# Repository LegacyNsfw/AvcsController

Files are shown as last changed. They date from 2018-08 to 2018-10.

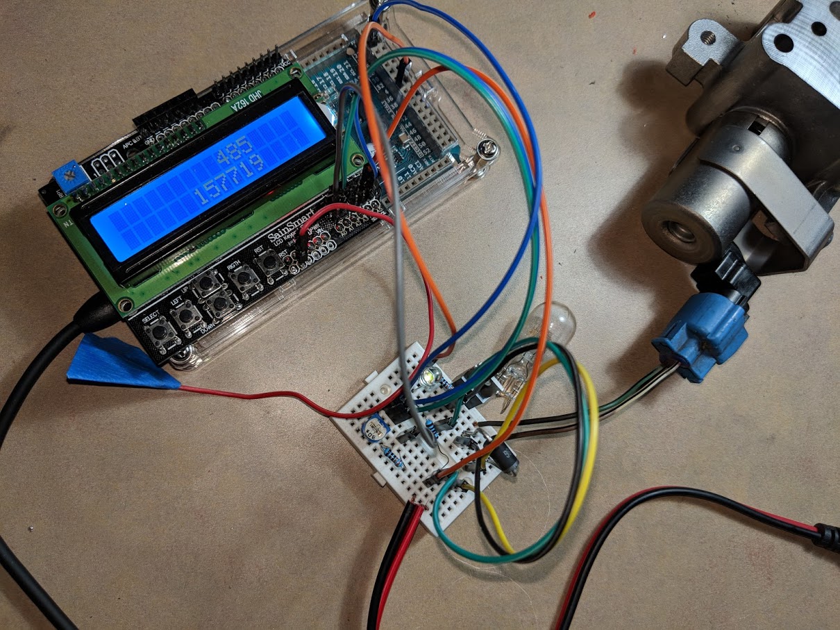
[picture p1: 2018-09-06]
Images/Hardware_SolenoidTesting.jpg

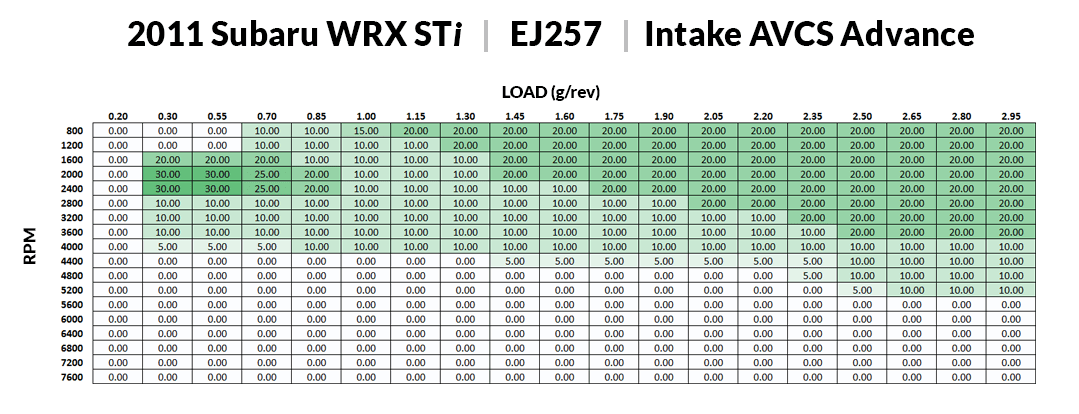
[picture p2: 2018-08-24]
Docs/subaru-avcs-intake-advance.png

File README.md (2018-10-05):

# AVCS Controller

A stand-alone exhaust AVCS controller for Subaru engines, based on an Arduino Due.

See the wiki for documentation.

See [this thread at RomRaider.com](http://www.romraider.com/forum/viewtopic.php?f=7&t=11237) for discussion.

All source code is licensed under the GNU GPL, version 3.

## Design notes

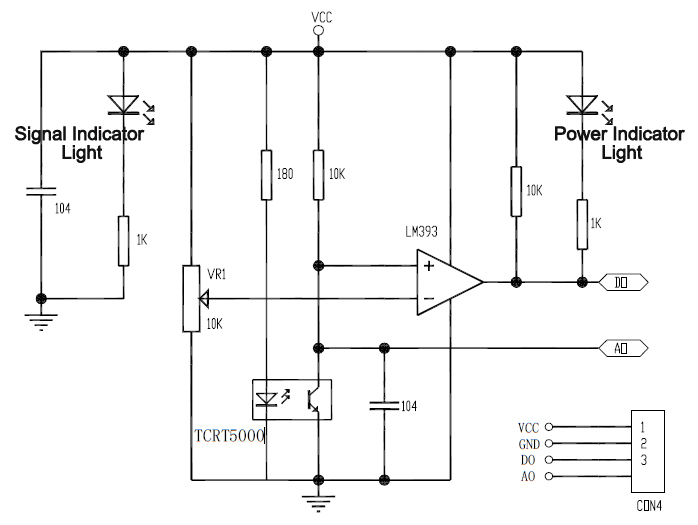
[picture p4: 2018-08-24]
Schematics/TCRT5000_LM393_Board.jpg

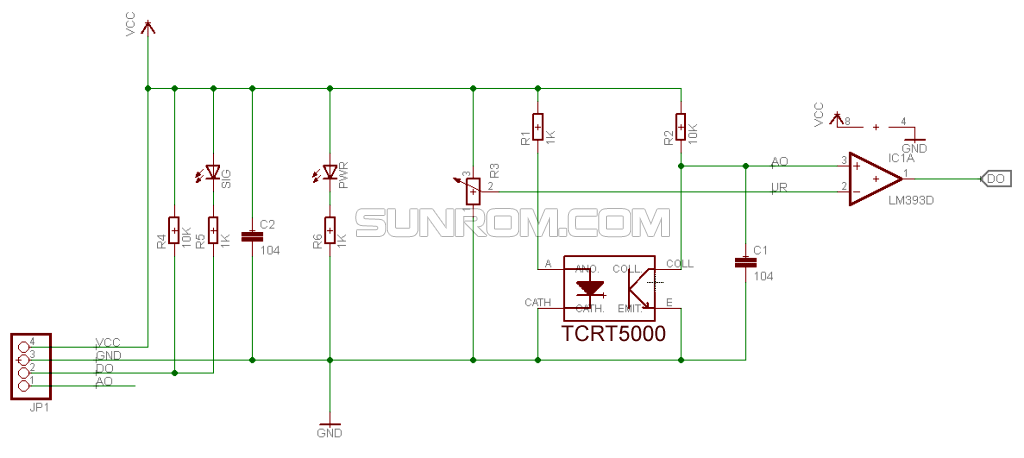
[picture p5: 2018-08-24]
Schematics/tcrt5000-schematic.gif

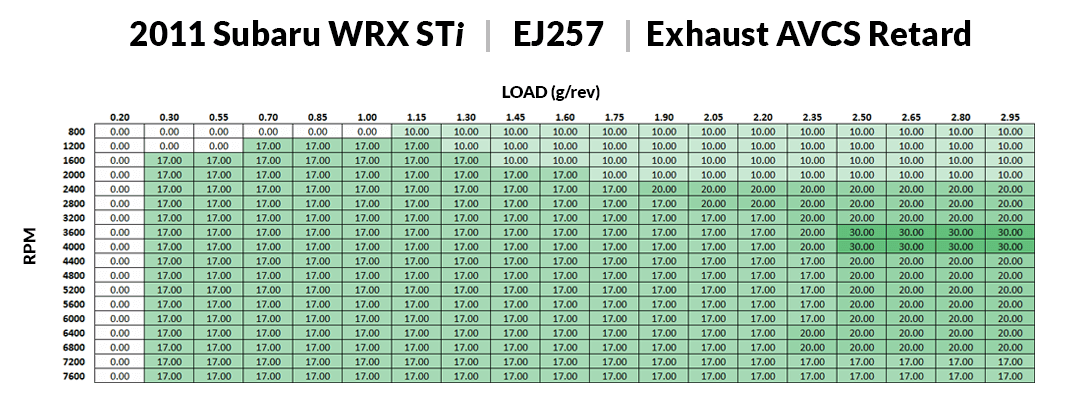
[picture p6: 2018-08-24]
Docs/subaru-avcs-exhaust-retard.png

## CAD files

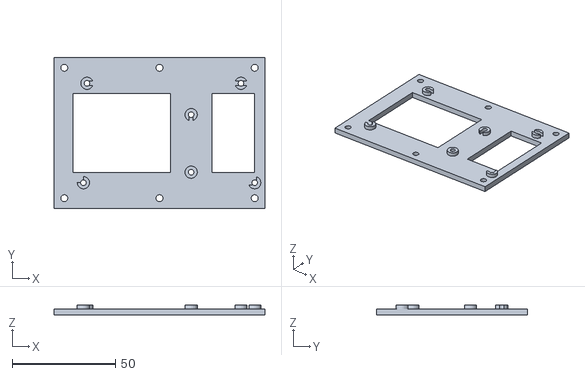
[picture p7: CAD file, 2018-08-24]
Models/ArduinoDueTwoPass.stl
102.3 x 73.2 x 5.00

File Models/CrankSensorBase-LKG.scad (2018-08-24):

width = 40;
height = 30;
baseDepth = 5;
lidDepth = 10;
ridgeTopWidth = 7;
ridgeBottomWidth = 10;
ridgeSpacing = 15;
ridgeHeight = 1.4;
mainHoleSpacing = 20;
thirdHoleSpacing = 17;
mainHoleDistanceFromEdge = 6;

sensorHoleCenter = 12.5; 
sensorWidth = 6.5;
sensorHeight = 11;

pulleyRadius = 48;
pulleyX = 41;
pulleyY = 40;

$fn = 20;

delta = 0;

module mountingHole(lid)
{
    cylinder(r = 1.6, h = 100, center = true);
    
    if (lid)
    {
        delta = 2.001;
    }
    else
    {
        delta = 1.999;
    }
    
    translate([0, 0, baseDepth + delta])
        cylinder(r = 3.4, h = 4, $fn = 6, center = true);
}

module holes(lid)
{
    translate([-17.5, 0, 0])
    {
        translate([mainHoleDistanceFromEdge, mainHoleSpacing / 2, 0])
        {
            mountingHole(lid);
        }

        translate([mainHoleDistanceFromEdge + thirdHoleSpacing, mainHoleSpacing / 2, 0])
        {
            mountingHole(lid);
        }

        translate([mainHoleDistanceFromEdge, -mainHoleSpacing / 2, 0])
        {
            mountingHole(lid);
        }
    }
}

module ridge()
{
    translate([-25, 0, -0.001])
    {
        rotate([0, 0, 90])
        rotate([90, 0 ,0])
        {
            linear_extrude(width + 10)
            {
                ridgeProfile =
                [
                    [-ridgeBottomWidth / 2, 0], 
                    [ridgeBottomWidth / 2, 0], 
                    [ridgeTopWidth / 2, ridgeHeight], 
                    [-ridgeTopWidth / 2, ridgeHeight]
                ];
                
                polygon(points=ridgeProfile);
            }
            //cube([width * 3, ridgeWidth, ridgeDepth], center=true);
        }
    }
}

module pinTrench()
{
    translate ([-14.5, 0, baseDepth])
    {
        cube([4, 10, 4], center = true);
    }
}

module ridges()
{
    translate([0, ridgeSpacing / 2, 0])
    {
        ridge();
    }

    translate([0, -ridgeSpacing / 2, 0])
    {
        ridge();
    }
}

module pulley()
{
    translate([pulleyX, -pulleyY, (-baseDepth/2) +2])
    {
        cylinder(r1 = pulleyRadius , r2 = pulleyRadius - 5, h = baseDepth+1, $fn=200);
        cylinder(r = pulleyRadius -4.5, h = baseDepth + lidDepth + 20, $fn=200);
    }
}

module base()
{
    difference()
    {
        union()
        {
            //pinTrench();            
            //pulley();
            
            difference()
            {
                translate([0, 0, baseDepth / 2])
                {
                    cube([width, height, baseDepth], center = true);
                }
                holes(false);
            }
        }
        
        pinTrench();      // 
        ridges();//
        
        translate([sensorHoleCenter, 0, 10])//
        {
            cube([sensorWidth, sensorHeight, 40], center = true);
        }
        
        pulley();//
    }
}

module lid()
{
    difference()
    {
        union()
        {   
            difference()
            {
                translate([0, 0, (lidDepth / 2) + baseDepth])
                {
                    cube([width, height, lidDepth], center = true);
                }
                holes(true);
            }
        }

        rightEdge = sensorHoleCenter + sensorWidth / 2;
        boardWidth = 33;
        position = rightEdge - (boardWidth / 2);
        translate([position, 0, 8.4])
        {
            cube([boardWidth, 14.5, 7], center = true);
        }

        translate([-width / 2, 0, baseDepth + 2])
        {
            cube([25, 10, 14], center = true);
        }

        pulley();
    }
}

//ridges();
//base();
lid();

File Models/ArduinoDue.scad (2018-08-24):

// Dimensions
totalWidth = 190.5; // 7.5"
totalLength = 190.5;
inch = 25.4;
halfInch = inch / 2;
quarterInch = inch / 4; // .25"
floorDepth = quarterInch;   // Real = .25 inches
edgeWidth = quarterInch;
bossHeight = quarterInch;
cavityDepth = 0.1 * inch;       // Real = 2 inches
boltRadius = 1.4;
dividerHeight = 56;
dividerDepth = inch;

$fn = 10;

// Boss
module boss(x, y)
{
    translate ([x, y, floorDepth + (bossHeight / 2) - 1])
    {
        difference()
        {
            cylinder(h = bossHeight, r = quarterInch, center = true, $fn = 20);
            cylinder(h = bossHeight + 1, r = boltRadius, center = true, $fn = 10);
        }
    }
}

difference()
{
    union()
    {
        cube([4.25 * inch, 2.75 * inch, floorDepth], false);

        // Arduino
        translate([0, 10, 0])
        {
            boss (14.25, 2.5); //  lower left
            boss (16,             2.5 + 5.1 + 27.9 + 15.2); // top left
            boss (14    + 52.5,        2.5 + 5.1); // lower Uno hole
            boss (14    + 52.5,        2.5 + 5.1 + 27.9); // upper Uno hole
            boss (14.05 + 52.5 + 24.1, 2.5 + 5.1 + 27.9 + 15.2); // upper right
            boss (12.00 + 85.3,        2.5); // lower right
        }
    }
    
    translate ([.25 * inch, .8 * inch, -10])
    {
        cube ([2 * inch, 1.2 * inch, inch], false);
    }
        
    translate ([inch, 0.25 * inch, -10])
    {
        cube ([1.25 * inch, 2.25 * inch, inch], false);
    }
    
    translate ([3 * inch, .85 * inch, -10])
    {
        cube ([1 * inch, 1.2 * inch, inch], false);
    }
}

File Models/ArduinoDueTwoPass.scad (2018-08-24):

// Dimensions
totalWidth = 190.5; // 7.5"
totalLength = 190.5;
inch = 25.4;
halfInch = inch / 2;
quarterInch = inch / 4; // .25"
floorDepth = 3;   // Real = .25 inches
edgeWidth = quarterInch;
bossHeight = 3;
cavityDepth = 0.1 * inch;       // Real = 2 inches
boltRadius = 1.4;
dividerHeight = 56;
dividerDepth = inch;
bossRadius = 3;

arduinoHeight = floorDepth + (bossHeight / 2) - 1;

    lowerLeftX = 14.25;
    upperLeftX = 16;
    upperRightX = 14.05 + 52.5 + 24.1;
    lowerRightX = 12.00 + 85.3;
    upperY = 2.5 + 5.1 + 27.9 + 15.2;
    lowerY = 2.5;
    unoX = 14 + 52.5;

// Boss
module boss(x, y, solid)
{
    translate ([x, y, 0])
    {
        if (solid > 0)
        {
            cylinder(h = bossHeight, r = bossRadius, center = true, $fn = 20);
        }
        else
        {
            cylinder(h = bossHeight + 30, r = boltRadius, center = true, $fn = 10);
        }
    }
}

module arduinoDue(solid)
{   
    translate([0, 0, (bossHeight / 2) - 1])
    {
        boss (lowerLeftX,          lowerY,                    solid); // lower left
        boss (16,                  upperY,                    solid); // upper left
        boss (unoX,                lowerY + 5.1,              solid); // lower Uno hole
        boss (unoX,                lowerY + 5.1 + 27.9,       solid); // upper Uno hole
        boss (upperRightX,         upperY,                    solid); // upper right
        boss (lowerRightX,         lowerY,                    solid); // lower right
        
        if (solid == 0)
        {
            // Lower left
            translate([lowerLeftX - 10, lowerY , (bossHeight / 2) - 2])
            {
                cube ([10, 10, 3]);
            }
            
            // Top two
            translate([upperLeftX, upperY - 1, (bossHeight / 2) - 2])
            {
                cube ([upperRightX - upperLeftX + 10, 2, 3]);
            }
            
            // Bottom right two
            translate([lowerRightX - (inch * 2) - 1, lowerY - 1, (bossHeight / 2) - 2])
            {
                cube ([inch * 2, 2, 3]);
            }  
  
            translate([lowerRightX - 1, lowerY, (bossHeight / 2) - 2])
            {
                cube ([2, 20, 3]);
            }  

            translate([lowerRightX - 3, lowerY, (bossHeight / 2) - 2])
            {
                cube ([2, 20, 3]);
            }  

            // Upper Uno hole
            translate([unoX - 1, lowerY + 23, (bossHeight / 2) - 2])
            {
                cube ([2, 10, 3]);
            }  
        }
    }
}

buffer = 5;
xOffset = 0;
yOffset = lowerY + (buffer * 1.5);
platformHeight = upperY - lowerY + (5 * buffer);
mountingHoleWidth = lowerRightX;
mountingHoleHeight = platformHeight - (2 * buffer);
echo("mountingHoleWidth = ", mountingHoleWidth);
echo("mountingHoleHeight = ", mountingHoleHeight);

module mountingHoles()
{
    translate([buffer, buffer, 0])
    {
        cylinder(r = boltRadius + .3, h = 20, center = true, $fn = 20);
    }
    
    translate([mountingHoleWidth, buffer, 0])
    {
        cylinder(r = boltRadius + .3, h = 20, center = true, $fn = 20);
    }

    translate([(mountingHoleWidth + buffer) / 2, buffer, 0])
    {
        cylinder(r = boltRadius + .3, h = 20, center = true, $fn = 20);
    }
}

difference()
{
    union()
    {
        cube([lowerRightX + buffer, platformHeight, floorDepth], false);

        // Arduino positive
        translate([xOffset, yOffset, floorDepth])
        {
            arduinoDue(1);
        }
    }

    // Arduino negative
    translate([xOffset, yOffset, floorDepth])
    {
        arduinoDue(0);
                
        translate ([lowerLeftX - buffer, lowerY + buffer, -10])
        {
            cube ([unoX - lowerLeftX - buffer, upperY - lowerY - (2 * buffer), inch], false);
        }
            
        translate ([unoX + (2 * buffer), lowerY + buffer, -10])
        {
            cube ([lowerRightX - unoX - (2 * buffer), upperY - lowerY - (2 * buffer), inch], false);
        }
        
    }

        mountingHoles();
        
        translate([0, mountingHoleHeight, 0])
        {
            mountingHoles();
        }

}

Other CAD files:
Models/CrankSensorBase.scad
Models/Case-Short.scad
Models/Case.scad
Models/PlxTieDown.scad
Models/RelayBracket.scad

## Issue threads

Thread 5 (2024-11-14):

2 Pin Cam Pos. Sensors

martino-dot, 2024-11-14:
Hi, I've been trying to figure out how to setup this controller, however I noticed that my EJ20X has a 2 pin cam position sensor, instead of a three pin. It seems that this sensor is an inductive sensor, instead of a hall effect sensor, and was trying to see how I could set it up with this code.

From what I've gathered, to try and make my sensor work, I would have to take these analogue inputs into the arduino, set thresholds for them, and assign them as digital, effectively converting them into the three pin sensor.

Is this the correct way to do that, and if not is there a better/proper way to do this?

martino-dot, 2024-12-04:
Update, what I've done to make this work is get a VR conditioner board that is typically used with the speeduino project, and use that. It converts the signals from analogue to digital, and lets this operate as it normally would.

martino-dot, 2024-12-25:
For anyone that runs across this in the future, a logic level converter should also be used for most of the things as I saw the zener diodes not giving consistent results. The VR conditioner boards run at 5v, so it's not very complicated to convert that to a 3.3v digital signal.

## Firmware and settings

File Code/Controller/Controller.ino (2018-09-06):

// Controller.ino
//
// Entry point for Dual AVCS controller.
//
// Requires:
//   Arduino Due
//   Sainsmart 1602 LCD/Keypad shield
//
// Recommended:
//   Arduino Due or Mega prototyping shield
//
// Arduino Pin Configuration:
// 
// Digital pins 4-9 are for LCD
// Digital/PWM pin 10 is LCD backlight
//
// Pin D3 = TIOA7 = left cam 
// Pin D11 = TIOA8 = right cam 
// Pin D2 = TIOA0 = crank
//
// Cam timers are triggered on rising and falling edges of cam signal
// Crank time is read 'manually' when interrupt is processed - would
// rather do a hardware capture but haven't got that figured out yet.
// 
// Analog input 0 is used for keypad keys
// Analog input 1 is used for crank sensor analog (which is only useful for diagnostics)
// Analog 8 = MAP sensor
// Analog 9 = input knob 1
// Analog 10 = input knob 2
// Analog 10-15 available for whatever else.
// 
// Digital pin 36 = PWM out for left cam
// Digital pin 38 = PWM out for right cam
//
// TX3 / RX3 = serial from PLX oil temperature, to PLX oil pressure
//
// Core AVCS functionality:
// When the signal from the crank trigger goes high, start timers.
// When the callbacks for the timers detect the sensor pulse, note the time since crank trigger.
// Elapsed time corresponds to cam phase angle.
// Use PID feedback to set AVCS solenoid PWM, to drive cam angle toward desired angle.

#include "SelfTest.h"
#include "Mode.h"
#include "ScreenNavigator.h"
#include "LiquidCrystal.h"
#include "DFR_Key.h"
#include "RollingAverage.h"
#include "ExhaustCamState.h"
#include "CrankState.h"
#include "InterruptHandlers.h"
#include "Globals.h"
#include "Screen.h"
#include "Utilities.h"
#include "PlxProcessor.h"
#include "Feedback.h"
#include "PeriodicJobs.h"
#include "IntervalRecorder.h"
#include "Terminal.h"
#include "Configuration.h"
#include "CurveTable.h"

//#include <..\Pwm_Lib\pwm_lib.h>
#include "pwm_lib\pwm_lib.h"
//#include "pwm_lib.h"

ScreenNavigator navigator;
LiquidCrystal lcd(8, 9, 4, 5, 6, 7); 
DFR_Key keys;
Mode mode;
PlxProcessor plx;
InterruptHandlers interruptHandlers;
unsigned iterationCounter;
IPeriodicJobs *jobs = IPeriodicJobs::GetInstance();
IIntervalRecorder *intervalRecorder = IIntervalRecorder::GetInstance();
ITerminal *terminal = ITerminal::GetInstance();
CurveTable *table = CurveTable::CreateExhaustCamTable();

// Do not change these at run-time!
//
// By default, the controller will discover the baseline cam
// angle at run-time, by measuring it shortly after startup,
// while the the solenoids are disabled. This kinda works, but
// you really need to hold a constant RPM for a few seconds to
// get a good baseline. (Idle RPM jumps around too much to be
// useful for this measurement.) Sometimes it'll be off by a
// couple degrees or so.
//
// Set onlyMeasureBaseline to force the controller to measure
// the cam baseline angle continuously, never attempting to
// control the cam angle. This is useful to determine the 
// static baseline angles to use.
//
int onlyMeasureBaseline = 0;
//
// Set the useStaticBaseline flag to skip the measurement step
// and use hard-coded baseline values instead of discovered
// baseline values. The values are in ExhaustCamState.cpp.
//
int useStaticBaseline = 1;

// Exhaust cam solenoid drivers
using namespace arduino_due::pwm_lib;
pwm<pwm_pin::PWML1_PC4> RightSolenoid; // pin 36, blue, passenger side
pwm<pwm_pin::PWML2_PC6> LeftSolenoid; // pin 38, yellow, driver side

// 300hz = 3.33ms
// = 3330.0 microseconds
// Period is defined in hundredths of a microsecond
#define PWM_PERIOD 333 * 1000

///////////////////////////////////////////////////////////////////////////////
// The setup function runs once when you press reset or power the board.
///////////////////////////////////////////////////////////////////////////////
void setup() {
	lcd.begin(16, 2);
	lcd.setCursor(0, 0);
	lcd.print("1234567890213456");
	lcd.setCursor(0, 1);
	lcd.print("1234567890213456");
	delay(100);
	lcd.clear();
	
	SelfTest();

	DisplayLine1[DisplayWidth] = 0;
	DisplayLine2[DisplayWidth] = 0;

	pinMode(A0, INPUT); // keypad
	pinMode(A1, INPUT); // crank angle sensor
	analogWrite(10, 60); // backlight
	
	pinMode(2, INPUT_PULLUP); // crank
	pinMode(3, INPUT_PULLUP); // left cam
	pinMode(11, INPUT_PULLUP); // right cam
	pinMode(13, OUTPUT); // onboard LED

	// This is the power supply for the TCRT5000 crank sensor
	// It draws 1ma, the output can source 15ma, so no worries.
	pinMode(53, OUTPUT);
	digitalWrite(53, HIGH);

	// Testing
	pinMode(22, OUTPUT);
	
	// pinMode(A8, INPUT); // MAP sensor
	// pinMode(A9, INPUT); // Knob?

	navigator.Initialize(&mode);
	plx.Initialize(&Serial3, &Serial2);	
	interruptHandlers.Initialize();
	mode.Initialize();
	jobs->Initialize();
	intervalRecorder->Initialize();
	terminal->Initialize();

	LeftCamError = -10;
	RightCamError = 10;

	LeftSolenoid.start(PWM_PERIOD, 0);
	RightSolenoid.start(PWM_PERIOD, 0);

	Serial.begin(115200);
}

///////////////////////////////////////////////////////////////////////////////
// This is invoked repeatedly by the Arduino core library.
///////////////////////////////////////////////////////////////////////////////
void loop()
{
	iterationCounter++;

	int key = keys.getKey();
	if (navigator.Update(key))
	{
		ClearScreen();
	}
	else
	{
		ClearScreenBuffer();
	}

	navigator.GetCurrentScreen()->Update();

	jobs->Update();
	mode.Update();
	plx.Update();
	terminal->Update();
	
	CamTargetAngle = table->GetValue(Crank.Rpm);

	// RPM jumps around a lot at idle, so rather than chasing noisy 
	// data I am just letting the cams rest. At least for now.
	// Might be fun to try creating overlap at idle, just to see if 
	// it starts to sound like an old-school muscle car...
	if ((mode.GetMode() == Mode::Running) && (Crank.Rpm > MINIMUM_EXAVCS_RPM) && !onlyMeasureBaseline)
	{
		float baseDuty = 44.0f;
		float ratio;
		float duty;

		if (LeftExhaustCam.Updated)
		{
			LeftExhaustCam.Updated = 0;

			LeftFeedback.Update(micros(), Crank.Rpm, LeftExhaustCam.Angle, CamTargetAngle);
			float ratio = (baseDuty + LeftFeedback.Output) / 100.0f;
			float duty = PWM_PERIOD * ratio;
			LeftSolenoid.set_duty((uint32_t)duty);
		}

		if (RightExhaustCam.Updated)
		{
			RightExhaustCam.Updated = 0;

			RightFeedback.Update(micros(), Crank.Rpm, RightExhaustCam.Angle, CamTargetAngle);
			ratio = (baseDuty + RightFeedback.Output) / 100.0f;
			duty = PWM_PERIOD * ratio;
			RightSolenoid.set_duty((uint32_t)duty);
		}
	}
	else
	{
		LeftFeedback.Reset(0);
		RightFeedback.Reset(1);

		LeftSolenoid.set_duty(0);
		RightSolenoid.set_duty(0);
	}

	LeftExhaustCam.PinState = (unsigned)digitalRead(3);
	RightExhaustCam.PinState = (unsigned)digitalRead(11);
	Crank.PinState = (unsigned)digitalRead(2);
	Crank.AnalogValue = (unsigned)analogRead(A1);

	LeftExhaustCam.Process();
	RightExhaustCam.Process();
	Crank.Process();
}

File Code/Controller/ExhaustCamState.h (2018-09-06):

#pragma once

///////////////////////////////////////////////////////////////////////////////
// Holds the state for a single exhaust cam and its associated pulse train
//
// TODO: Migrate ExhaustCamTiming to the interface pattern
///////////////////////////////////////////////////////////////////////////////
class ExhaustCamState
{
private:
	
	enum CycleStates
	{
		Start,
		Pulse1,
		Pulse2,
		End,
	};

public:
	// Nonzero for left cam, zero for right cam.
	unsigned Left;

	// Time between start-of-cam-pulse events.
	unsigned AverageInterval;

	// Time between start of pulse and end of pulse.
	unsigned PulseDuration;

	// Each cam instance maintains an RPM value so it can be sanity-checked against the others.
	unsigned Rpm;
	unsigned CalibrationCountdown; // May go slightly negative due to race conditions
	CycleStates CycleState;
	unsigned TimeSinceCrankSignal;
	float Baseline; 
	float Angle;
	unsigned PinState; // set by the .ino code, should match PulseState
	unsigned PulseState; // set by the interrupt handler, should match PinState
	unsigned Timeout;
	unsigned Updated;

	ExhaustCamState(int left)
	{
		Left = left;
		AverageInterval = 0;
		PulseDuration = 0;
		Rpm = 0;
		CalibrationCountdown = 0;
		TimeSinceCrankSignal = 0;
		Baseline = 0;
		Angle = 0;
		PinState = 0;
		PulseState = 0;
		Timeout = 0;
		Updated = 0;
	}

	void StartCycle();
	void BeginPulse(unsigned camInterval, unsigned crankInterval);
	void EndPulse(unsigned camInterval);

	// Clean up if wraparound happened due to a race condition
	void Process()
	{
		if (CalibrationCountdown > 10000)
		{
			CalibrationCountdown = 0;
		}
	}
};

///////////////////////////////////////////////////////////////////////////////
// Self-test the cam timing code
///////////////////////////////////////////////////////////////////////////////
void SelfTestExhaustCamTiming();

///////////////////////////////////////////////////////////////////////////////
// Global instances of ExhaustCamTiming
///////////////////////////////////////////////////////////////////////////////
extern ExhaustCamState LeftExhaustCam;
extern ExhaustCamState RightExhaustCam;

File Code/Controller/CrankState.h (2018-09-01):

#pragma once

class CrankState
{
public:
	unsigned CalibrationCountdown;
	unsigned Rpm;
	unsigned AverageInterval;
	unsigned PulseDuration;
	unsigned PinState;
	unsigned PulseState;
	unsigned Timeout;
	unsigned AnalogValue;

	CrankState()
	{
		CalibrationCountdown = 0;
		Rpm = 0;
		PulseDuration = 0;
		PinState = 0;
		PulseState = 0;
		Timeout = 0;
	}

	void BeginPulse(unsigned interval);
	void EndPulse(unsigned interval);

	void Process()
	{
		// Clean up if wraparound happened due to a race condition
		if (CalibrationCountdown > 10000)
		{
			CalibrationCountdown = 0;
		}
	}
};

extern CrankState Crank;

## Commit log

2018-08-24 Migrated from Mercurial.
    [Arduino Solenoid With Placeholder Power Supply.fzz, Arduino Solenoid.fzz, ArduinoDue.scad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]
2018-09-01 Renamed the 'synchronize' phase of initialization to 'calibrate' (it was poorly named from the start).
2018-09-04 Missed a couple of things when I changed the way UpdateRollingAverage works.
2018-09-06 Added pictures of the crank timing sensor.
